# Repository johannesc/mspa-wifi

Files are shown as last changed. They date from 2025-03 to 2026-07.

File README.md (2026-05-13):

# mspa-wifi

This project explains how to add Wi-Fi connectivity to the M-Spa Aurora Urban U-AU062 using ESPHome,
enabling integration with Home Assistant. This is done by adding an ESP32-S2 module inside the
remote control that intercepts the traffic between the remote control and control box.

Note that currently this takes full control over the filter pump and heater which means that this will
disable the control of these from the remote control. The remote control can still be used to control
other functions (like UV and bubbles).

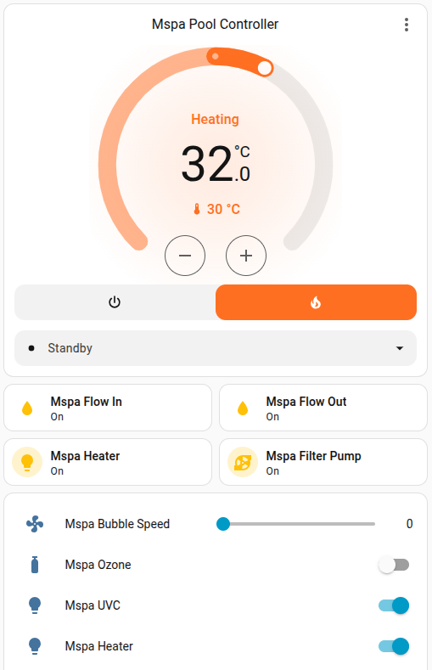
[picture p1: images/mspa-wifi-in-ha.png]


# Build your own

## Required Items

 * 1 pcs [S2 Mini V1.0.0 ESP32-S2 module](https://www.amazon.se/dp/B0BGPD6CV5)
 * 2 pcs [1k Ohm restistor](https://www.amazon.se/dp/B0DWK5KSBF)
 * [2.54 mm header](https://www.amazon.se/dp/B0DYDBSTGJ)
 * Connector for the remote
 * Some cables, soldering iron, glue gun etc.

## Program Your ESP-32 module, command line version

Read [Getting Started with the ESPHome Command Line](https://esphome.io/guides/getting_started_command_line/)

Download or clone the repository, e.g.:

```
git clone https://github.com/johannesc/mspa-wifi.git
```

Create a esphome/secrets.yaml with content:

```
wifi_ssid: <Your Wi-Fi SSID>
wifi_password: <Your Wi-Fi Passoword>

mspa_password: <A password of your choice>
mspa_api_key: <Home Assistant>
```

An esphome API key can be created [here](https://esphome.io/components/api.html)

Connect your module using a USB-C cable and program it (press and hold the "O" button while pressing and releasing the RST button to put in programming mode):
```
$ pip install esphome
$ cd esphome
$ esphome run mspa-wifi.yaml
```
## Add the Mspa device to Home Assistant

Go to Settings/Devices & Services/ESPHome and press "ADD DEVICE". If this is your first ESPHome
device you probably need to add the ESPHome integration first.

For more information see [Connecting your device to Home Assistant](https://esphome.io/guides/getting_started_hassio.html#connecting-your-device-to-home-assistant).

## If you don't have Home Assistant

Make sure to add `reboot_timeout: 0s` to the `mspa-wifi.yaml` to prevent it from rebooting every 15 minutes.

## Modifying your Remote

Below picture shows how to connect your hardware. Everything fits inside the M-Spa remote control
(it is a bit tight though). The 1 k resistors are used to limit the current as the M-Spa uses 5 v
while the ESP32-S2 uses 3.3 v.

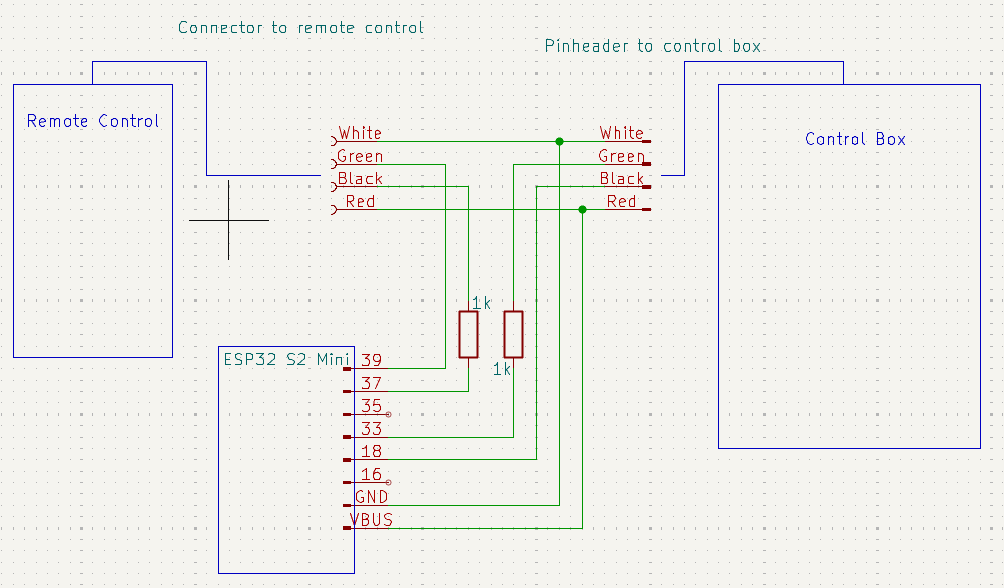
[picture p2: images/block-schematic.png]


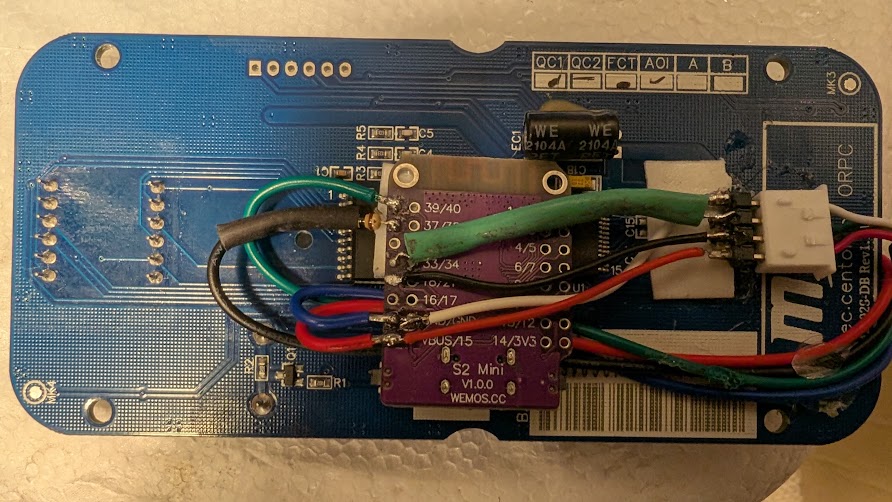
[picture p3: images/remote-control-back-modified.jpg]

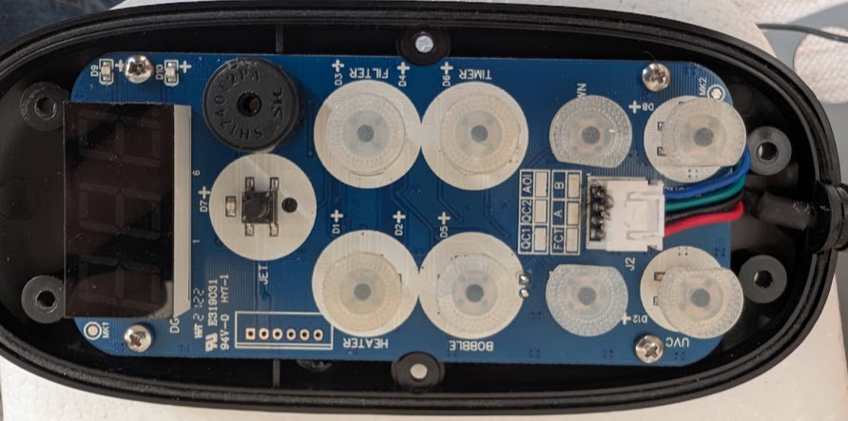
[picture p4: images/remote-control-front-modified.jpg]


## Ready To Use

You should now be ready to control your M-Spa through Home Assistant or through your browser
at [http://mspa.local/](http://mspa.local/).

# M-Spa protocol and Hardware Description

## Hardware

### Control Box
The control board inside the control box:
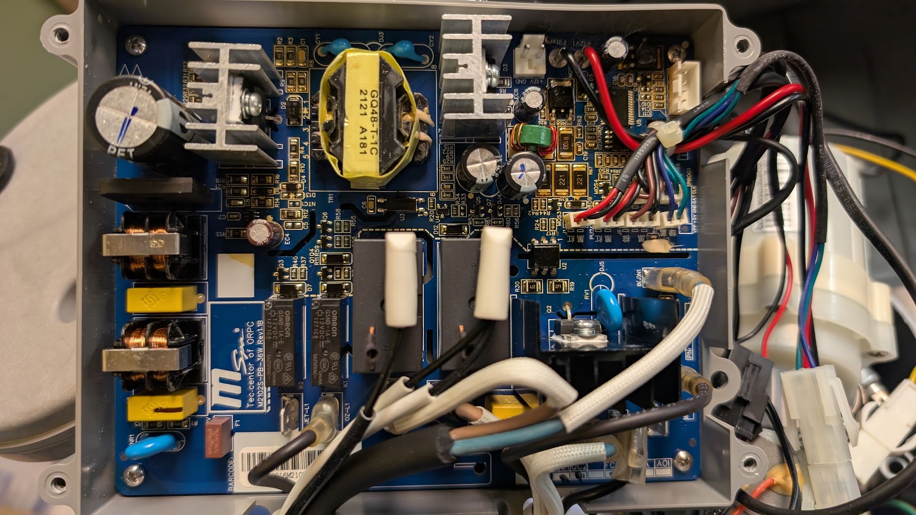
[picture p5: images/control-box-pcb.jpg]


The microcontroller is a PIC16F723A:

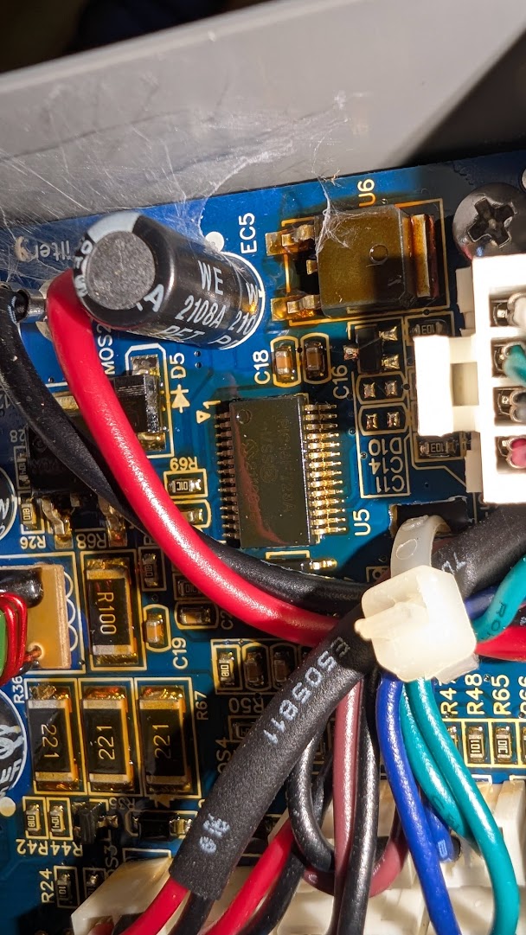
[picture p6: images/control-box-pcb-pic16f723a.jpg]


The connector to the remote control can be seen in the upper right corner. The pinout:

| Color | Description |
|---|---|
| White | GND |
| Green | Tx (control box to remote control) |
| Black | Rx (remote control to control box) |
| Red | +5v |

### Remote Control

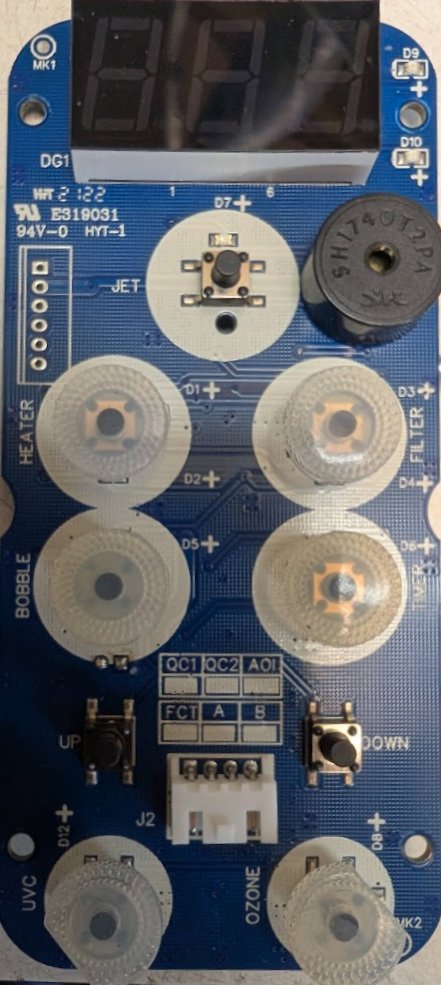
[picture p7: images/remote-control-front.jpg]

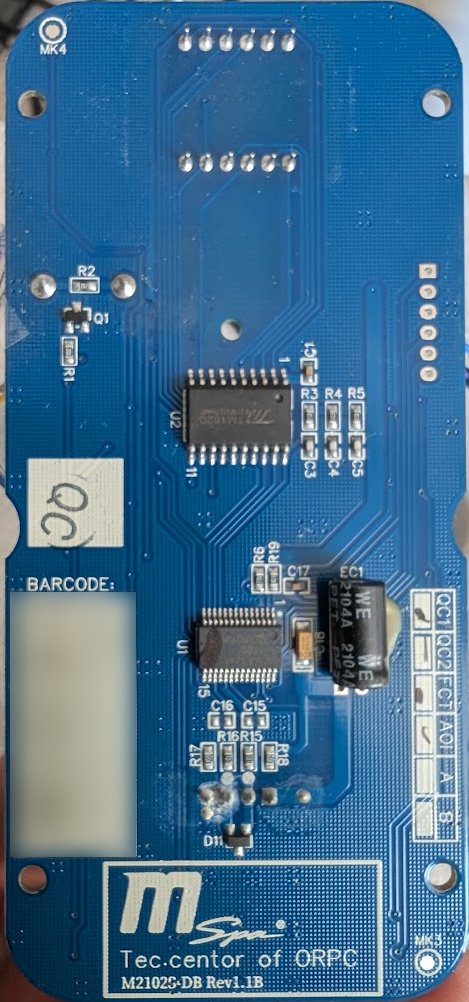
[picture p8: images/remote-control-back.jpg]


The microcontroller is a PIC16F723A. The chip at the top is a TM1620 (LED driver).

Unmounted Pin Header

| Pin # | Description |
|---|---|
| 1 (top) | PIC16F723A Pin #1 (/MCLR) |
| 2 | PIC16F723A Pin #19 (VDD) |
| 3 | GND |
| 4 | PIC16F723A Pin #28 (ICSPDAT) |
| 5 | PIC16F723A Pin #27 (ICSPCLK) |
| 6 | NC? |

## Protocol

UART Settings 9600 bps 8N1. 4 byte packets.

See `scripts/mspa_decoder.py` for example decoding of the protocol.

Captured data:

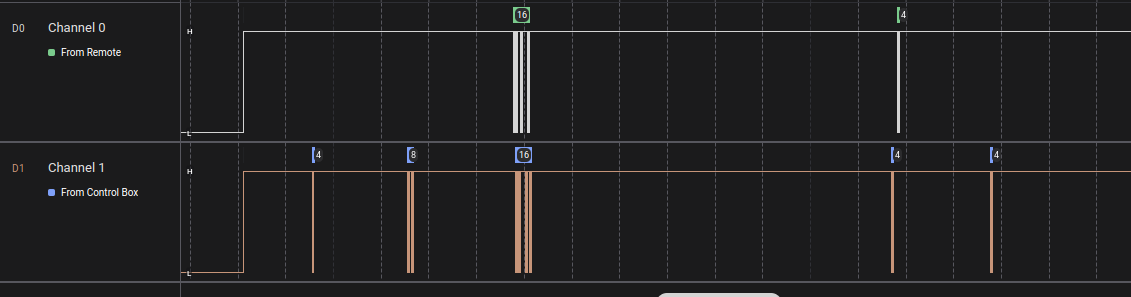
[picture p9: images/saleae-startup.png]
Captured startup communication


### Example Packets

#### From Control Box:
| Data | Description |
|---|---|
|0xA5  | Packet start |
|0x06  | Temperature reading |
|0x1C  | Temp = 0x1C/2 = 14.0 degrees  |
|0xC7  | Checksum = 0xA5 + 0x06 + 0X1C)|

More examples:

    0xA5 0x08 0x00 0xAD
    0xA5 0x0B 0x86 0x36

    Flow On?
    A5 08 01 AE

    A5 0B 86 36

#### From Remote

    Timestamp: Data
    0.30: A5 03 00 A8
    1.81: A5 0D 00 B2
    3.31: A5 0E 00 B3
    4.81: A5 15 00 BA
    4.91: A5 01 00 A6
    6.31: A5 02 00 A7

    Press - one time (temp at 40 degrees)
    110.67: A5 16 00 BB
    110.67: A5 04 28 D1

    Press - until 35 degrees:
    173.09: A5 04 23 CC

    Heater On:
    A5 02 01 A8
    A5 16 00 BB

    Filter On:
    A5 02 01 A8
    A5 16 00 BB

### Power On Sequence

    /dev/ttyUSB0: 5.46: New Command: A5 09 00 AE: Unknown command A5 09 00 AE
    /dev/ttyUSB0: 5.66: New Command: A5 07 0C B8: Unknown command A5 07 0C B8
    /dev/ttyUSB1: 5.89: New Command: A5 0B 00 B0: Unknown command A5 0B 00 B0
    /dev/ttyUSB1: 5.89: New Command: A5 0A 00 AF: Unknown command A5 0A 00 AF
    /dev/ttyUSB0: 5.89: New Command: A5 0B 86 36: Unknown command A5 0B 86 36
    /dev/ttyUSB0: 5.89: New Command: A5 0A 01 B0: Unknown command A5 0A 01 B0
    /dev/ttyUSB1: 5.90: New Command: A5 11 00 B6: Unknown command A5 11 00 B6
    /dev/ttyUSB0: 5.91: New Command: A5 11 00 B6: Unknown command A5 11 00 B6
    /dev/ttyUSB1: 5.91: New Command: A5 10 00 B5: Unknown command A5 10 00 B5
    /dev/ttyUSB0: 5.92: New Command: A5 10 00 B5: Unknown command A5 10 00 B5
    /dev/ttyUSB0: 6.06: New Command: A5 06 2F DA: Temp report: 23.5 °C
    /dev/ttyUSB1: 6.09: New Command: A5 01 00 A6: Heater enabled: False
    /dev/ttyUSB0: 6.87: New Command: A5 08 00 AD: Flow report: In: False, out: False
    /dev/ttyUSB0: 7.08: Old Command: A5 06 2F DA: Temp report: 23.5 °C
    /dev/ttyUSB1: 7.49: New Command: A5 02 00 A7: Set filter: False
    /dev/ttyUSB0: 7.89: Old Command: A5 08 00 AD: Flow report: In: False, out: False
    /dev/ttyUSB0: 8.09: Old Command: A5 06 2F DA: Temp report: 23.5 °C
    /dev/ttyUSB0: 8.90: Old Command: A5 08 00 AD: Flow report: In: False, out: False
    /dev/ttyUSB1: 8.99: New Command: A5 03 00 A8: Set bubble speed: 0
    /dev/ttyUSB0: 9.11: Old Command: A5 06 2F DA: Temp report: 23.5 °C
    /dev/ttyUSB0: 9.92: Old Command: A5 08 00 AD: Flow report: In: False, out: False
    /dev/ttyUSB0: 10.12: Old Command: A5 06 2F DA: Temp report: 23.5 °C
    /dev/ttyUSB1: 10.50: New Command: A5 0D 00 B2: Unknown command A5 0D 00 B2
    /dev/ttyUSB1: 10.90: New Command: A5 0F 00 B4: Unknown command A5 0F 00 B4
    /dev/ttyUSB0: 10.93: Old Command: A5 08 00 AD: Flow report: In: False, out: False
    /dev/ttyUSB0: 11.13: Old Command: A5 06 2F DA: Temp report: 23.5 °C
    /dev/ttyUSB0: 11.94: Old Command: A5 08 00 AD: Flow report: In: False, out: False
    /dev/ttyUSB1: 12.00: New Command: A5 0E 00 B3: Ozone enabled: False
    /dev/ttyUSB0: 12.15: Old Command: A5 06 2F DA: Temp report: 23.5 °C
    /dev/ttyUSB0: 12.96: Old Command: A5 08 00 AD: Flow report: In: False, out: False
    /dev/ttyUSB0: 13.16: Old Command: A5 06 2F DA: Temp report: 23.5 °C
    /dev/ttyUSB1: 13.51: New Command: A5 15 00 BA: Set UVC: False
    /dev/ttyUSB1: 13.61: Old Command: A5 01 00 A6: Heater enabled: False
    /dev/ttyUSB0: 13.97: Old Command: A5 08 00 AD: Flow report: In: False, out: False
    /dev/ttyUSB0: 14.17: Old Command: A5 06 2F DA: Temp report: 23.5 °C
    /dev/ttyUSB0: 14.98: Old Command: A5 08 00 AD: Flow report: In: False, out: False
    /dev/ttyUSB1: 15.01: Old Command: A5 02 00 A7: Set filter: False
    ....

#### Set Target Temp
    /dev/ttyUSB1: 75.14: Old Command: A5 02 00 A7: Set filter: False
    /dev/ttyUSB1: 75.57: Old Command: A5 01 00 A6: Heater enabled: False
    /dev/ttyUSB1: 75.57: Old Command: A5 02 00 A7: Set filter: False
    /dev/ttyUSB1: 75.57: Old Command: A5 03 00 A8: Set bubble speed: 0
    /dev/ttyUSB1: 75.57: Old Command: A5 0D 00 B2: Unknown command A5 0D 00 B2
    /dev/ttyUSB1: 75.57: Old Command: A5 0E 00 B3: Ozone enabled: False
    /dev/ttyUSB1: 75.57: Old Command: A5 15 00 BA: Set UVC: False
    /dev/ttyUSB1: 75.57: New Command: A5 16 00 BB: Unknown command A5 16 00 BB
    /dev/ttyUSB1: 75.57: New Command: A5 04 25 CE: Set temp: 37 °C
    /dev/ttyUSB0: 75.77: Old Command: A5 08 00 AD: Flow report: In: False, out: False
    /dev/ttyUSB0: 75.97: Old Command: A5 06 30 DB: Temp report: 24.0 °C
    /dev/ttyUSB1: 76.65: Old Command: A5 03 00 A8: Set bubble speed: 0
    /dev/ttyUSB0: 76.78: Old Command: A5 08 00 AD: Flow report: In: False, out: False
    /dev/ttyUSB0: 76.99: Old Command: A5 06 30 DB: Temp report: 24.0 °C
    /dev/ttyUSB0: 77.80: Old Command: A5 08 00 AD: Flow report: In: False, out: False
    /dev/ttyUSB0: 78.00: Old Command: A5 06 2F DA: Temp report: 23.5 °C
    /dev/ttyUSB1: 78.15: Old Command: A5 0D 00 B2: Unknown command A5 0D 00 B2

### Decoded Protocol

| Offset | Description |
|---|---|
| 0 | Packet start |
| 1 | Command (see table below) |
| 2 | Parameter |
| 3 | Checksum (sum of offset 0, 1, 2)|

| Command | Description |
|---|---|
| 0x01 | Set Heater |
| 0x02 | Set Filter |
| 0x03 | Set Bubble |
| 0x04 | Set Target Temperature |
| 0x05 | ? |
| 0x06 | Temp Report (sent each second)  |
| 0x07 | ? |
| 0x08 | Flow Report (sent each second)  |
| 0x09 | ? |
| 0x0A | ? |
| 0x0B | Get/Report timer. Sent 1 / min from remote (value 0x00) filter pump replies direct with a value that increase for every hour |
| 0x0C | ? |
| 0x0D | Sent 8 times / min (7.5 s period) from remote |
| 0x0E | Set Ozone |
| 0x0F | ? |
| 0x10 | ? |
| 0x11 | ? |
| 0x12 | ? |
| 0x13 | ? |
| 0x14 | ? |
| 0x15 | Set UVC |
| 0x16 | Inflate |
| 0x17 | ? |

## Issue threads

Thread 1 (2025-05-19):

Failed config on component

Rav3nholm, 2025-05-19:
Been trying to get this to work on my MSPA but have run into problems.
Don't know if its on my end the issue lies or something else.

Have a ESP32 S2 up and running with a base code but I cant get your code to work.
Get this error when validating:

`INFO ESPHome 2024.12.4
INFO Reading configuration /config/esphome/mspa.yaml...
ERROR Unable to load component mspa_wifi:
Traceback (most recent call last):
  File "/esphome/esphome/loader.py", line 177, in _lookup_module
    module = importlib.import_module(f"esphome.components.{domain}")
             ^^^^^^^^^^^^^^^^^^^^^^^^^^^^^^^^^^^^^^^^^^^^^^^^^^^^^^^
  File "/usr/lib/python3.11/importlib/__init__.py", line 126, in import_module
    return _bootstrap._gcd_import(name[level:], package, level)
           ^^^^^^^^^^^^^^^^^^^^^^^^^^^^^^^^^^^^^^^^^^^^^^^^^^^^
  File "<frozen importlib._bootstrap>", line 1206, in _gcd_import
  File "<frozen importlib._bootstrap>", line 1178, in _find_and_load
  File "<frozen importlib._bootstrap>", line 1149, in _find_and_load_unlocked
  File "<frozen importlib._bootstrap>", line 690, in _load_unlocked
  File "<frozen importlib._bootstrap_external>", line 936, in exec_module
  File "<frozen importlib._bootstrap_external>", line 1074, in get_code
  File "<frozen importlib._bootstrap_external>", line 1004, in source_to_code
  File "<frozen importlib._bootstrap>", line 241, in _call_with_frames_removed
  File "/config/esphome/components/mspa_wifi/__init__.py", line 7
    <!DOCTYPE html>
    ^
SyntaxError: invalid syntax
Failed config

mspa_wifi: [source /config/esphome/mspa.yaml:59]

  Component not found: mspa_wifi.
  - id: mspa_wifi_1
    uart_box_to_remote_id: uart_box_to_remote
    uart_remote_to_box_id: uart_remote_to_box`

Am not used to components and Python in ESPhome so it could be that I have missed something.
I have installed this manually on in my HA environment and not through "PIP".

Would love to make this work and help you out in testing, have 2 MSPA hot tubs of different models that could be used in testing.

Rav3nholm, 2025-05-21:
This is my mspa.yaml

```yaml
esphome:
  name: mspa
  friendly_name: MSPA

esp32:
  board: esp32-s2-saola-1
  framework:
    type: arduino

# Enable logging
logger:
  level: INFO  # Set to DEBUG if you are having issues!

api:
  encryption:
    key: "xxx"

ota:
  - platform: esphome
    password: "xxx"

wifi:
  ssid: !secret wifi_ssid
  password: !secret wifi_password

  # Enable fallback hotspot (captive portal) in case wifi connection fails
  ap:
    ssid: "Mspa Fallback Hotspot"
    password: "xxx"

captive_portal:

external_components:
  # use rtttl and dfplayer from ESPHome's dev branch in GitHub
  - source:
      type: git
      url: https://github.com/johannesc/mspa-wifi
      ref: main
    components: [ mspa_wifi ]

uart:
  - id: uart_box_to_remote
    rx_pin: # green cable to box
      number: GPIO33
      inverted: false
    tx_pin: # green cable to remote
      number: GPIO39
      inverted: false
    baud_rate: 9600
    rx_buffer_size: 512
  - id: uart_remote_to_box
    rx_pin: # black cable to remote
      number: GPIO37
      inverted: false
    tx_pin: # black cable to box
      number: GPIO18
      inverted: false
    baud_rate: 9600
    rx_buffer_size: 512

mspa_wifi:
  - id: mspa_wifi_1
    uart_box_to_remote_id: uart_box_to_remote
    uart_remote_to_box_id: uart_remote_to_box

binary_sensor:
  - platform: mspa_wifi
    flow_in:
      name: "Flow In"
    flow_out:
      name: "Flow Out"
    filter_pump:
      name: "Filter Pump"
    uvc:
      name: "UVC"
    ozone:
      name: "Ozone"
    heater:
      name: "Heater"

sensor:
  - platform: mspa_wifi
    water_temperature:
      name: "Temperature"
  - platform: mspa_wifi
    target_water_temperature:
      name: "Target Temperature"
      on_value:
      - lambda: |-
          id(target_water_temp).publish_state(x);
  - platform: mspa_wifi
    bubble_speed:
      name: "Bubble Speed"
      on_value:
      - lambda: |-
          id(target_bubble_speed).publish_state(x);
number:
  - platform: template
    name: "Target water temp"
    id: target_water_temp
    min_value: 24
    max_value: 40
    step: 1
    icon: "mdi:thermometer"
    optimistic: true
    restore_value: false
    set_action:
      - lambda: |-
          ESP_LOGI("number_template", "New value from HA: %f", x);
          id(mspa_wifi_1)->set_target_water_temperature(x);
  - platform: template
    name: "Bubble Speed"
    id: target_bubble_speed
    min_value: 0
    max_value: 3
    step: 1
    optimistic: false
    restore_value: false
    set_action:
      - lambda: |-
          ESP_LOGI("bubble speed template", "New value from HA: %f", x);
          id(mspa_wifi_1)->set_bubble_speed((uint8_t)x);
```
Now after I modified the component part of my code it does validate and writes to my ESP32 so that great!
I havent tried it on my SPA yet, will do that later this week or weekend.
Reporting back on the results then!

Closed 2025-06-06.

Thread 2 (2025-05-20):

filter pump switches off after few minutes

phrozendevil, 2025-05-20:
Hi Johannes, first if all... a really great project!
I built and flashed the ESP-module succesfully whithout problems after a little research with ESPHome and python.

The main problem is when i switch on the filter pump over remote, after a few minutes it switches off, so i can't let it run over night.
Also the correct state of UVC isn't shown in WebUI, how to find out which command-byte it has?

Is it possible to add action buttons for all functions in the WebUI when i directly connect to mspa.local? because i have no HomeAssistant

btw i have an MSpa Ottoman with UVC and Bubble (but without speed setting

sorry for writing this all in the issues, but i don't know how to contact you otherwise

best regards from germany
Thorsten

phrozendevil, 2025-05-20:
it looks like 0x10 is my UVC, with this i see the state

johannesc, 2025-05-20:
Hi Thorsten,

Great that you got started! I did this project as a "winter"-project so that I could use it once I had my pool up an running. Unfortunately the pool is still not up, so I have not tested the filter more than a short time.

But one problem with my solution is that for some commands the remote repeat the command at an interval. This means that if I turn on the air (bubble) pump, the remote is not aware of the change and will turn it off again, In order to get around this I intercept the commands from the remote and, if overridden (i.e. changed from HA), I overwrite the value in the packet with the HA one.  If you then change the value on the remote again, the remote is in control again. You can see this in the code:

```
     case CMD_SET_BUBBLE:
      {
        uint8_t bubble_speed = packet_[2];

        if (bubble_speed != bubble_remote_) {
          // The bubble speed was changed at the remote
          // The remote is now "in control"
          bubble_remote_ = bubble_speed;
          actual_state_.bubble = bubble_speed;
        } else if (bubble_speed != actual_state_.bubble) {
          packet_[2] = actual_state_.bubble;
          fill_crc(packet_);
          ESP_LOGI(TAG, "%s: Bubble speed is overridden from %d to %d", name_, bubble_speed, actual_state_.bubble);
        }
```

 I suspect that a similar solution is needed for other commands.

Regarding your question about the WebUI it should be possible to add full control. So far I only added the "Bubble Speed" and "Target Water Temperature". The WebUI have the same control possibility as in Home Assistant. I am not that good at ESPHome yaml, but you should be able to add more in a similar way as I have done. For on/off items perhaps you could use a  ["switch" template](https://www.home-assistant.io/integrations/switch.template/)?

I wish I had more time, but maybe I get some more during the summer. Otherwise you are always welcome to make pull-requests if you do any improvements.

phrozendevil, 2025-05-26:
Hi Johannes,

the filter pump is running now without problems. The problem was because i have no HomeAssistant, so the EspHome does a automatic reboot every 15 minutes. I added "reboot_timeout: 0s" in the mspa-wifi.yaml and now it stays on.

i'm about to make additions for the buttons in the webui, but i also have the problem with time ;-)

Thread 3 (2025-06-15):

Set temperature not working

CTBruker, 2025-06-15:
Hi first thanks for the great work! Set bubbles and all get values are working as expected! But setting  the temperature in home assistant do not have any effect of the set temperature in the remote control!

phrozendevil, 2025-06-19:
The main problem is that the remote overwrites all commands from ESP, you have to catch them and modify them before sending to pool. I added the switching of all functions and modified the heating part to switch off heater when target temp is reached. I don't know how to do a pullrequest, may johannesc can add the changes to his version!?
But it's still a develop version, i didn't test all circumstances.
Some things are in german, just edit them ;-) Best regards from Germany!

mspa_wifi.cpp
`#include "mspa_wifi.h"
#include "esphome/core/log.h"
#include "esphome/core/hal.h"

#define MSPA_START_BYTE 0xA5
#define MSPA_PACKET_LEN 4
#define MAX_PACKET_TIME_MS 100

#define CMD_TEMP_REPORT 0x06
#define CMD_FLOW_REPORT 0x08

#define CMD_SET_HEATER 0x01
#define CMD_SET_FILTER 0x02
#define CMD_SET_BUBBLE 0x03
#define CMD_SET_TARGET_TEMP 0x04
#define CMD_SET_OZONE 0x0E
#define CMD_SET_UVC 0x10    //can be 0x15 on other pools!
#define CMD_SET_UNKNOWN_0D 0x0D
#define CMD_SET_UNKNOWN_16 0x16

#define TAG "MspaWifi"

namespace esphome
{
  namespace mspa_wifi
  {
    void MspaWifi::setup()
    {
      mspa_box_to_remote_ = new MspaCom(box_to_remote_uart_, this, "-->");
      mspa_remote_to_box_ = new MspaCom(remote_to_box_uart_, this, "<--");
    }

    void MspaWifi::MspaCom::fill_crc(uint8_t *packet)
    {
      uint8_t crc = 0;
      for (int i = 0; i < (MSPA_PACKET_LEN - 1); i++)
      {
        crc += packet[i];
      }
      packet[3] = crc;
    }

    void MspaWifi::set_bubble_speed(uint8_t speed)
    {
      mspa_remote_to_box_->set_bubble_speed(speed);
    }

    void MspaWifi::set_switch_command(uint8_t command_id, bool enabled)
    {
      switch (command_id)
      {
        case CMD_SET_HEATER:
		  if (enabled) mspa_remote_to_box_->set_filter(enabled);
          mspa_remote_to_box_->set_heater(enabled);
          break;
        case CMD_SET_FILTER:
          mspa_remote_to_box_->set_filter(enabled);
          break;
        case CMD_SET_OZONE:
		  if (enabled) mspa_remote_to_box_->set_filter(enabled);
          mspa_remote_to_box_->set_ozone(enabled);
          break;
        case CMD_SET_UVC:
		  if (enabled) mspa_remote_to_box_->set_filter(enabled);
          mspa_remote_to_box_->set_uvc(enabled);
          break;
      }
    }

    void MspaWifi::MspaCom::set_bubble_speed(uint8_t speed)
    {
      // This will be used in handle_packet
      actual_state_.bubble = speed;
      mspa_->bubble_speed_sensor_->publish_state(actual_state_.bubble);

      // Also send a packet directly so that bubble speed is updated directly
      uint8_t packet[MSPA_PACKET_LEN] = {MSPA_START_BYTE, CMD_SET_BUBBLE, speed, 0};
      fill_crc(packet);
      send_packet(packet);
    }

    void MspaWifi::set_target_water_temperature(float target)
    {
      mspa_remote_to_box_->set_target_water_temperature(target);
      target_water_temperature_sensor_->publish_state(target);
    }

    void MspaWifi::MspaCom::set_target_water_temperature(float target)
    {
      ESP_LOGI(TAG, "Set target temp to %f", target);
      uint8_t packet[MSPA_PACKET_LEN] = {MSPA_START_BYTE, CMD_SET_TARGET_TEMP, (uint8_t)target, 0};
      fill_crc(packet);
      send_packet(packet);
    }

    void MspaWifi::MspaCom::set_heater(bool enabled)
    {
      actual_state_.heater = enabled;
	  ESP_LOGI(TAG, "Set heater %s", enabled ? "ENABLE" : "DISABLE");
      uint8_t data = enabled ? 1 : 0;
      uint8_t packet[MSPA_PACKET_LEN] = {MSPA_START_BYTE, CMD_SET_HEATER, data, 0};
      fill_crc(packet);
      send_packet(packet);
    }

    void MspaWifi::MspaCom::set_filter(bool enabled)
    {
	  actual_state_.filter = enabled;
      ESP_LOGI(TAG, "Set filter %s", enabled ? "ENABLE" : "DISABLE");
      uint8_t data = enabled ? 1 : 0;
      uint8_t packet[MSPA_PACKET_LEN] = {MSPA_START_BYTE, CMD_SET_FILTER, data, 0};
      fill_crc(packet);
      send_packet(packet);
    }

    void MspaWifi::MspaCom::set_ozone(bool enabled)
    {
      actual_state_.ozone = enabled;
	  ESP_LOGI(TAG, "Set ozone %s", enabled ? "ENABLE" : "DISABLE");
      uint8_t data = enabled ? 1 : 0;
      uint8_t packet[MSPA_PACKET_LEN] = {MSPA_START_BYTE, CMD_SET_OZONE, data, 0};
      fill_crc(packet);
      send_packet(packet);
    }

    void MspaWifi::MspaCom::set_uvc(bool enabled)
    {
      actual_state_.uvc = enabled;
	  ESP_LOGI(TAG, "Set uvc %s", enabled ? "ENABLE" : "DISABLE");
      uint8_t data = enabled ? 1 : 0;
      uint8_t packet[MSPA_PACKET_LEN] = {MSPA_START_BYTE, CMD_SET_UVC, data, 0};
      fill_crc(packet);
      send_packet(packet);
    }

    void MspaWifi::MspaCom::send_packet(const uint8_t *packet)
    {
      ESP_LOGI(TAG, "%s: Send packet: %02X %02X %02X %02X", name_, packet[0], packet[1], packet[2], packet[3]);
      for (int i = 0; i < MSPA_PACKET_LEN; i++)
      {
        uart_->write_byte(packet[i]);
      }
    }

    bool MspaWifi::MspaCom::handle_packet()
    {
      uint8_t crc = 0;
      for (int i; i < (MSPA_PACKET_LEN - 1); i++)
      {
        crc += packet_[i];
      }

      if (crc != packet_[MSPA_PACKET_LEN - 1])
      {
        ESP_LOGE(TAG, "%s: Bad CRC", name_);
        return false;
      }

      switch (packet_[1])
      {
      case CMD_TEMP_REPORT:
      {
        float water_temperature = (float)packet_[2] / 2.0f;
		ESP_LOGI(TAG, "%s: Water temp report %f", name_, water_temperature);
        mspa_->water_temperature_sensor_->publish_state(water_temperature);
        break;
      }
      case CMD_FLOW_REPORT:
      {
        bool flow_in = (packet_[2] & 0x01) != 0;
        bool flow_out = (packet_[2] & 0x02) != 0;
        ESP_LOGI(TAG, "%s: Flow in: %s, out: %s", name_, flow_in ? "On" : "Off", flow_out ? "On" : "Off");
        mspa_->flow_in_binary_sensor_->publish_state(flow_in);
        mspa_->flow_out_binary_sensor_->publish_state(flow_out);
        break;
      }
      case CMD_SET_TARGET_TEMP:
      {
        float target_temperature = packet_[2];
        mspa_->target_water_temperature_sensor_->publish_state(target_temperature);
        ESP_LOGI(TAG, "%s: Set target temp %f", name_, target_temperature);
        break;
      }
      case CMD_SET_HEATER:
      {
        bool heater_enabled = packet_[2];

        if (heater_enabled != remote_state_.heater) {
		  remote_state_.heater = heater_enabled;
		  actual_state_.heater = heater_enabled;
	    } else if (heater_enabled != actual_state_.heater) {
			if (mspa_->water_temperature_sensor_->has_state() && mspa_->target_water_temperature_sensor_->has_state() &&
    (actual_state_.heater == 1) && (mspa_->water_temperature_sensor_->get_state() >= mspa_->target_water_temperature_sensor_->get_state())) {
			  packet_[2] = 0x00;
		      fill_crc(packet_);
			  ESP_LOGI(TAG, "%s: Water temp %.1f reached target temp %.1f, NOT heating till temp falls", name_, mspa_->water_temperature_sensor_->get_state(), mspa_->target_water_temperature_sensor_->get_state());
		  } else {
			  packet_[2] = actual_state_.heater;
		      fill_crc(packet_);
		      ESP_LOGI(TAG, "%s: Heater state is overridden from %d to %d", name_, heater_enabled, actual_state_.heater);
		  }
		}

        if (mspa_->heater_switch_)
        {
          mspa_->heater_switch_->publish_state(actual_state_.heater);
        }
        ESP_LOGI(TAG, "%s: Heater enabled: %s", name_, actual_state_.heater ? "true" : "false");
		ESP_LOGI(TAG, "%s: Heater remote state: %s", name_, remote_state_.heater ? "true" : "false");

        break;
      }
      case CMD_SET_FILTER:
      {
        bool filter_enabled = packet_[2];

		if (filter_enabled != remote_state_.filter) {
		  remote_state_.filter = filter_enabled;
		  actual_state_.filter = filter_enabled;
	    } else if (filter_enabled != actual_state_.filter) {
		  packet_[2] = actual_state_.filter;
		  fill_crc(packet_);
		  ESP_LOGI(TAG, "%s: Filter state is overridden from %d to %d", name_, filter_enabled, actual_state_.filter);
		}
        if (mspa_->filter_pump_switch_ != NULL)
        {
          mspa_->filter_pump_switch_->publish_state(actual_state_.filter);
        }
        ESP_LOGI(TAG, "%s: Filter enabled: %s", name_, actual_state_.filter ? "true" : "false");
		ESP_LOGI(TAG, "%s: Filter remote state: %s", name_, remote_state_.filter ? "true" : "false");
        break;
      }
      case CMD_SET_BUBBLE:
      {
        uint8_t bubble_speed = packet_[2];

        if (bubble_speed != remote_state_.bubble) {
          // The bubble speed was changed at the remote
          // The remote is now "in control"
          remote_state_.bubble = bubble_speed;
          actual_state_.bubble = bubble_speed;
        } else if (bubble_speed != actual_state_.bubble) {
          packet_[2] = actual_state_.bubble;
          fill_crc(packet_);
          ESP_LOGI(TAG, "%s: Bubble speed is overridden from %d to %d", name_, bubble_speed, actual_state_.bubble);
        }

        mspa_->bubble_speed_sensor_->publish_state(packet_[2]);
        ESP_LOGI(TAG, "%s: Bubble speed: %d", name_, packet_[2]);
        break;
      }
      case CMD_SET_OZONE:
      {
        bool ozone_enabled = packet_[2] == 0x01;
        if (ozone_enabled != remote_state_.ozone) {
		  remote_state_.ozone = ozone_enabled;
		  actual_state_.ozone = ozone_enabled;
	    } else if (ozone_enabled != actual_state_.ozone) {
		  packet_[2] = actual_state_.ozone;
		  fill_crc(packet_);
		  ESP_LOGI(TAG, "%s: Ozone state is overridden from %d to %d", name_, ozone_enabled, actual_state_.ozone);
		}
		if (mspa_->ozone_switch_)
        {
          mspa_->ozone_switch_->publish_state(actual_state_.ozone);
        }
        ESP_LOGI(TAG, "%s: Ozone enabled: %s", name_, actual_state_.ozone ? "true" : "false");
		ESP_LOGI(TAG, "%s: Ozone remote state: %s", name_, remote_state_.filter ? "true" : "false");
        break;
      }
      case CMD_SET_UVC:
      {
        bool uvc_enabled = packet_[2];
		if (uvc_enabled != remote_state_.uvc) {
		  remote_state_.uvc = uvc_enabled;
		  actual_state_.uvc = uvc_enabled;
	    } else if (uvc_enabled != actual_state_.uvc) {
		  packet_[2] = actual_state_.uvc;
		  fill_crc(packet_);
		  ESP_LOGI(TAG, "%s: UVC state is overridden from %d to %d", name_, uvc_enabled, actual_state_.uvc);
		}
        if (mspa_->uvc_switch_)
        {
          mspa_->uvc_switch_->publish_state(actual_state_.uvc);
        }
        ESP_LOGI(TAG, "%s: UVC enabled: %s", name_, actual_state_.uvc ? "true" : "false");
		ESP_LOGI(TAG, "%s: UVC remote state: %s", name_, remote_state_.filter ? "true" : "false");
        break;
      }
      default:
      {
        ESP_LOGE(TAG, "%s: Unknown packet: %02X %02X %02X %02X", name_, packet_[0], packet_[1], packet_[2], packet_[3]);
        break;
      }
      }
      return true;
    }
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
Randolf22, 2025-06-19:
Hi,

Just to confirm – for you, is the heating control actually working, including setting the target temperature?

I’ve now tested everything via the web interface as well, but the behavior remains the same: the heating turns off automatically after a few seconds, and setting a target temperature has no effect.

Additionally, I’ve noticed that I’m seeing some “unknown packages” in the logs or data stream. Do you see the same on your side?

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

phrozendevil, 2025-06-19:
Maybe i changed other files too, i will have a look later.

phrozendevil, 2025-06-23:
here are all my files with timer control for the heater. but because my pool has only one bubble speed i changed this to a normal switch, the original code is commented out. Webinterface V3 and the most in german.
maybe JohannesC can combine this with his code? or i finally find out how a pullrequest works ;-)

[https://drive.google.com/file/d/15JLOBKLaJK6sBXwsAFC9FcnZAyIB6S4e/view?usp=sharing](url)

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

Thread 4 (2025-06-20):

step-by-step instructions?

schnaidi, 2025-06-20:
Hey, hey, first of all, thank you so much for putting in the effort and trying everything to get the pools working. You have my deepest respect and appreciation.

I'm a complete noob, and this is all completely new territory for me.

But I would like to be able to control my pool via Home Assistant.

I can install the hardware easily, but unfortunately I can't get the programming and insertion, reading the data, etc. right. I've been trying for a week now, even though it's probably well explained.

But unfortunately, I can't get it to work.

Could someone write me a step-by-step guide on how to integrate something so that it works, or so that I at least see some progress and don't have to give up? :(

Or could someone send me a video showing what the integration with Home Assistant should look like, or how to integrate it?

phrozendevil, 2025-06-23:
Hey schnaidi,

where exactly does it fail? installing python? installing esphome?
do you have Windows or another OS?

schnaidi, 2025-06-23:
Hey, hey, first of all, thanks for your message and replying.

I read in the other post that you're also from Germany. Would it be possible to connect with you directly? I'm relatively new to this topic and I've probably made a few mistakes.
I managed to integrate it into Home Assistant, for example, but when I use the ESP32 on my remote control, for example, my remote doesn't work at all, or is that normal? And I don't get any data via Home Assistant.

The question can actually be closed or considered closed, since I've at least already gotten it into Home Assistant.

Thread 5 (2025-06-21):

Does this work with other MSpa?

gustafnilklint, 2025-06-21:
I have an MSpa where the "remote" is built into the external pump unit. Like this model:

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

Have anyone tried this project with such pump?

johannesc, 2025-06-25:
I have not tested with my own pool with a separate remote. What is the exact model of this one? When I search it looks like a "Mspa Naval F-NA062W" which seems to come with a phone application?

gustafnilklint, 2025-06-26:
Unfortunately my model is a bit older, with the pump-unit without Wifi capability.
I think the model is called MSpa MONO Frame or something similar.

gustafnilklint, 2025-08-07:
A bit of follow up on this topic:
I have put together the hardware and connected it to my spa.

It seem to be working to some extent. I can send commands that successfully toggle the heater, pump, bubbles and ozone. But after a few seconds the heater turn off again together with a beep from the remote.
But at least it seem to be able to send commands that is accepted by the box..

I cannot see any "state" from the pool. It is all showing as unavailable.

I see tons of logs like this:
"Bad start 0x00"

Any thoughts on what can be the reason behind these issues?

johannesc, 2025-08-10:
I am guessing that something is wrong with the receiving data from the pump unit. Check the connections to make sure that they are correct and properly connected.

I have still not put up my pool for this season and hence not tested this project in "real life". Maybe I get some time going forward, but until then, don't expect so much activity from my side here :)

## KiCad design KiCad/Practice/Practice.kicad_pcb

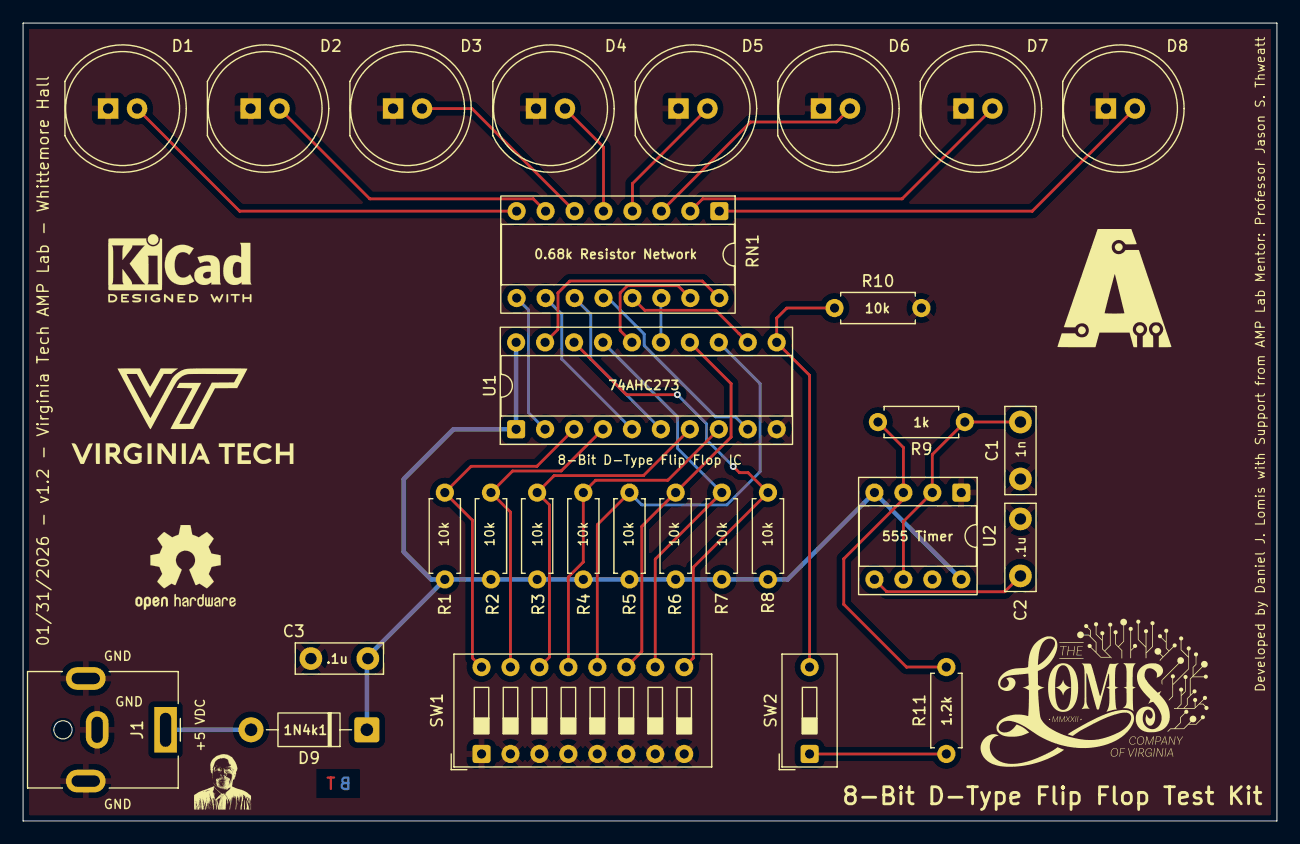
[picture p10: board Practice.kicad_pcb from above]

Board: 4 copper layers, 110.0 x 70.0 mm, 29 parts (0 on the bottom side), 32 nets.

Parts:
C1: 1n; C_Disc_D7.5mm_W2.5mm_P5.00mm
C2, C3: 100n; C_Disc_D7.5mm_W2.5mm_P5.00mm
D1, D2, D3, D4, D5, D6, D7, D8: LED; LED_D10.0mm
D9: 1N4001; D_DO-41_SOD81_P10.16mm_Horizontal
J1: Barrel_Jack_MountingPin; BarrelJack_CUI_PJ-063AH_Horizontal
R1, R2, R3, R4, R5, R6, R7, R8, R10: 10k; R_Axial_DIN0207_L6.3mm_D2.5mm_P7.62mm_Horizontal
R9: 1k; R_Axial_DIN0207_L6.3mm_D2.5mm_P7.62mm_Horizontal
R11: 1.2k; R_Axial_DIN0207_L6.3mm_D2.5mm_P7.62mm_Horizontal
RN1: R_Pack08; DIP-16_W7.62mm_Socket
SW1: SW_DIP_x08; SW_DIP_SPSTx08_Slide_9.78x22.5mm_W7.62mm_P2.54mm
SW2: SW_DIP_x01; SW_DIP_SPSTx01_Slide_9.78x4.72mm_W7.62mm_P2.54mm
U1: 74AHC273; DIP-20_W7.62mm_Socket
U2: ICM7555xP; DIP-8_W7.62mm_Socket

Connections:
+5V: C3.1, D9.1 (K), R1.1, R2.1, R3.1, R4.1, R5.1, R6.1, R7.1, R8.1, U1.1 (~Mr), U1.20 (VCC), U2.4 (R), U2.8 (VCC)
GND: C1.1, C2.2, C3.2, D1.1 (K), D2.1 (K), D3.1 (K), D4.1 (K), D5.1 (K), D6.1 (K), D7.1 (K), D8.1 (K), J1.2, J1.MP (MountPin), R10.2, SW1.1, SW1.2, SW1.3, SW1.4, SW1.5, SW1.6, SW1.7, SW1.8, U1.10 (GND), U2.1 (GND)
unnamed: D1.2 (A), RN1.8 (R8.1)
unnamed: D2.2 (A), RN1.7 (R7.1)
unnamed: D3.2 (A), RN1.6 (R6.1)
unnamed: D4.2 (A), RN1.5 (R5.1)
unnamed: D5.2 (A), RN1.4 (R4.1)
unnamed: D6.2 (A), RN1.3 (R3.1)
unnamed: D7.2 (A), RN1.2 (R2.1)
unnamed: D8.2 (A), RN1.1 (R1.1)
unnamed: D9.2 (A), J1.1
unnamed: R11.1, SW2.1
unnamed: RN1.16 (R1.2), U1.19 (Q7)
unnamed: RN1.15 (R2.2), U1.16 (Q6)
unnamed: RN1.14 (R3.2), U1.15 (Q5)
unnamed: RN1.13 (R4.2), U1.12 (Q4)
unnamed: RN1.12 (R5.2), U1.9 (Q3)
unnamed: RN1.11 (R6.2), U1.6 (Q2)
unnamed: RN1.10 (R7.2), U1.5 (Q1)
unnamed: RN1.9 (R8.2), U1.2 (Q0)
unnamed: R10.1, SW2.2, U1.11 (Cp)
unnamed: R1.2, SW1.16, U1.3 (D0)
unnamed: R2.2, SW1.15, U1.4 (D1)
unnamed: R3.2, SW1.14, U1.7 (D2)
unnamed: R4.2, SW1.13, U1.8 (D3)
unnamed: R5.2, SW1.12, U1.13 (D4)
unnamed: R6.2, SW1.11, U1.14 (D5)
unnamed: R7.2, SW1.10, U1.17 (D6)
unnamed: R8.2, SW1.9, U1.18 (D7)
unnamed: C2.1, U2.5 (CV)
unnamed: R9.2, R11.2, U2.3 (Q)
unnamed: C1.2, R9.1, U2.2 (TR), U2.6 (THR)

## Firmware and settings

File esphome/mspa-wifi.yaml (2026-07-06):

substitutions:
  device_name: mspa
  device_password: !secret mspa_password
  device_api_key: !secret mspa_api_key

esphome:
  name: ${device_name}
  on_boot:
    priority: -100
    then:
      - delay: 10s
      - number.set:
          id: mspa_bubble_speed
          value: 0
      - switch.turn_off: mspa_ozone_switch
      - switch.turn_on: mspa_uvc_switch

esp32:
  board: lolin_s2_mini
  variant: esp32s2
  framework:
    type: esp-idf

wifi:
  ssid: !secret wifi_ssid
  password: !secret wifi_password

  # Enable fallback hotspot (captive portal) in case wifi connection fails
  ap:
    ssid: "esp-${device_name}"
    password: "${device_password}"

captive_portal:

# Enable logging
logger:
  level: INFO  # Set to DEBUG if you are having issues!
  #baud_rate: 0 # disable logging over uart

api:
  encryption:
    key: "${device_api_key}"

ota:
  platform: esphome
  password: "${device_password}"

web_server:
  port: 80
  ota: false
#  auth:
#    username: admin
#    password: "${device_password}"

external_components:
  - source: components
    components: [ mspa_wifi ]

uart:
  - id: uart_box_to_remote
    rx_pin: # green cable to box
      number: GPIO33
      inverted: false
    tx_pin: # green cable to remote
      number: GPIO39
      inverted: false
    baud_rate: 9600
    rx_buffer_size: 512
  - id: uart_remote_to_box
    rx_pin: # black cable to remote
      number: GPIO37
      inverted: false
    tx_pin: # black cable to box
      number: GPIO18
      inverted: false
    baud_rate: 9600
    rx_buffer_size: 512

mspa_wifi:
  id: mspa_wifi_1
  uart_box_to_remote_id: uart_box_to_remote
  uart_remote_to_box_id: uart_remote_to_box
  uvc_command: 0x15
  jet_command: 0x0D

  # Sensors
  water_temperature:
    id: mspa_water_temperature
    name: "Temperature"
    state_class: "measurement"
    unit_of_measurement: "°C"
    device_class: "temperature"
    accuracy_decimals: 1

  # Binary sensors
  flow_in:
    name: "Flow In"
  flow_out:
    name: "Flow Out"

  # Switches
  filter_pump:
    name: "Filter Pump"
    on_turn_off:
      climate.control:
        id: climate_thermostat
        mode: "OFF"

  uvc:
    name: "UVC"
    id: mspa_uvc_switch

  ozone:
    name: "Ozone"
    id: mspa_ozone_switch
    restore_mode: ALWAYS_OFF
    on_turn_on:
      - script.execute: mspa_ozone_auto_off
    on_turn_off:
      - script.stop: mspa_ozone_auto_off

  heater:
    id: mspa_heater
    name: "Heater"

  jet:
    name: "Jet"
    id: mspa_jet_switch

  # Number controls
  target_water_temperature:
    name: "Target Temperature"
    id: mpsa_target_temperature
    min_value: 10

  bubble_speed:
    name: "Bubble Speed"
    id: mspa_bubble_speed
    max_value: 3
    on_value:
      then:
        - lambda: |-
            ESP_LOGI("yaml", "on_value: bubble_speed changed to %f", x);
        - if:
            condition:
              lambda: 'return x > 0;'
            then:
              - script.execute: mspa_bubble_speed_auto_off
            else:
              - script.stop: mspa_bubble_speed_auto_off

  inflate:
    name: "Inflate"
    id: mspa_inflate

script:
  - id: mspa_bubble_speed_auto_off
    mode: restart
    then:
      - delay: 300s
      - number.set:
          id: mspa_bubble_speed
          value: 0
  - id: mspa_ozone_auto_off
    mode: restart
    then:
      - delay: 7200s
      - switch.turn_off: mspa_ozone_switch

sensor:
  - platform: uptime
    type: seconds
    name: Uptime Sensor
  - platform: internal_temperature
    name: "Internal Temperature"
    id: int_temp

climate:
  - platform: thermostat
    name: "Pool Controller"
    id: climate_thermostat
    sensor: mspa_water_temperature
    min_heating_off_time: 10s
    min_heating_run_time: 10s
    min_idle_time: 10s
    visual:
      min_temperature: 10
      max_temperature: 40
      temperature_step: 0.5
    heat_action:
      - switch.turn_on: mspa_heater
    idle_action:
      - switch.turn_off: mspa_heater
    default_preset: Standby
    preset:
      - name: Hibernate
        default_target_temperature_low: 10
      - name: Standby
        default_target_temperature_low: 35
      - name: Swim
        default_target_temperature_low: 40
    on_state:
      - lambda: |-
          id(mpsa_target_temperature).control(x.target_temperature);

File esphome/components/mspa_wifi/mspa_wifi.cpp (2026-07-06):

#include "mspa_wifi.h"
#include "esphome/core/log.h"
#include "esphome/core/hal.h"

#define MSPA_START_BYTE 0xA5
#define MSPA_PACKET_LEN 4
#define MAX_PACKET_TIME_MS 100

#define CMD_TEMP_REPORT 0x06
#define CMD_FLOW_REPORT 0x08
#define CMD_TIMER_REPORT 0x0B

#define CMD_SET_HEATER 0x01
#define CMD_SET_FILTER 0x02
#define CMD_SET_BUBBLE 0x03
#define CMD_SET_TARGET_TEMP 0x04
#define CMD_GET_TIMER 0x0B
#define CMD_SET_OZONE 0x0E
#define CMD_SET_JET 0x0D
#define CMD_SET_INFLATE 0x16
#define CMD_JET_REPORT 0x18

#define TAG "MspaWifi"

namespace esphome
{
  namespace mspa_wifi
  {
    void MspaWifi::set_box_to_remote_uart(uart::UARTComponent *box_uart) {
      mspa_box_to_remote_ = new MspaBoxToRemoteCom(box_uart, this, "-->");
    }

    void MspaWifi::set_remote_to_box_uart(uart::UARTComponent *remote_uart) {
      mspa_remote_to_box_ = new MspaRemoteToBoxCom(remote_uart, this, uvc_command_, jet_command_, "<--");
    }

    void MspaWifi::MspaCom::fill_crc(uint8_t *packet)
    {
      uint8_t crc = 0;
      for (int i = 0; i < (MSPA_PACKET_LEN - 1); i++)
      {
        crc += packet[i];
      }
      packet[3] = crc;
    }

    void MspaWifi::set_bubble_speed(uint8_t speed)
    {
      mspa_remote_to_box_->set_bubble_speed(speed);
    }

    void MspaWifi::set_heater(bool enabled) {
      if (enabled) {
        set_filter(true); // Heater requires filter pump running, also enable that
      }
      mspa_remote_to_box_->set_heater(enabled);
    }

    void MspaWifi::set_filter(bool enabled) {
      mspa_remote_to_box_->set_filter(enabled);
    }

    void MspaWifi::set_ozone(bool enabled) {
      if (enabled) {
        set_filter(true); // Ozone requires filter pump running, also enable that
      }
      mspa_remote_to_box_->set_ozone(enabled);
    }

    void MspaWifi::set_uvc(bool enabled) {
      if (enabled) {
        set_filter(true); // UVC requires filter pump running, also enable that
      }
      mspa_remote_to_box_->set_uvc(enabled);
    }

    void MspaWifi::set_jet(bool enabled) {
      if (enabled) {
        set_filter(true); // Jet requires filter pump running, also enable that
      }
      mspa_remote_to_box_->set_jet(enabled);
    }

    void MspaWifi::set_inflate(bool enabled) {
      mspa_remote_to_box_->set_inflate(enabled);
    }

    void MspaWifi::set_target_water_temperature(float target)
    {
      mspa_remote_to_box_->set_target_water_temperature(target);
    }

    void MspaWifi::MspaRemoteToBoxCom::set_bubble_speed(uint8_t speed)
    {
      mspa_->actual_state_.bubble = speed; // This will be used in handle_packet

      if (mspa_->target_bubble_speed_number_ != NULL) {
        mspa_->target_bubble_speed_number_->publish_state(mspa_->actual_state_.bubble);
      }
      uint8_t packet[MSPA_PACKET_LEN] = {MSPA_START_BYTE, CMD_SET_BUBBLE, speed, 0};
      fill_crc(packet);
      send_packet(packet);
    }

    void MspaWifi::MspaRemoteToBoxCom::set_target_water_temperature(float target)
    {
      ESP_LOGI(TAG, "Set target temp to %f", target);
      if (mspa_->target_water_temperature_number_ != NULL) {
        mspa_->target_water_temperature_number_->publish_state(target);
      }
      uint8_t packet[MSPA_PACKET_LEN] = {MSPA_START_BYTE, CMD_SET_TARGET_TEMP, (uint8_t)target, 0};
      fill_crc(packet);
      send_packet(packet);
    }

    void MspaWifi::MspaRemoteToBoxCom::set_heater(bool enabled)
    {
      ESP_LOGI(TAG, "Set heater %s", enabled ? "ENABLE" : "DISABLE");
      mspa_->actual_state_.heater = enabled; // This will be used in handle_packet
      if (mspa_->heater_switch_) {
        mspa_->heater_switch_->publish_state(mspa_->actual_state_.heater);
      }
      uint8_t data = enabled ? 1 : 0;
      uint8_t packet[MSPA_PACKET_LEN] = {MSPA_START_BYTE, CMD_SET_HEATER, data, 0};
      fill_crc(packet);
      send_packet(packet);
    }

    void MspaWifi::MspaRemoteToBoxCom::set_filter(bool enabled)
    {
      ESP_LOGI(TAG, "Set filter %s", enabled ? "ENABLE" : "DISABLE");
      mspa_->actual_state_.filter = enabled; // This will be used in handle_packet
      mspa_->remote_state_.filter = enabled; // Keep in sync to prevent F1
      if (mspa_->filter_pump_switch_ != NULL) {
        mspa_->filter_pump_switch_->publish_state(mspa_->actual_state_.filter);
      }
      uint8_t data = enabled ? 1 : 0;
      uint8_t packet[MSPA_PACKET_LEN] = {MSPA_START_BYTE, CMD_SET_FILTER, data, 0};
      fill_crc(packet);
      send_packet(packet);
    }

    void MspaWifi::MspaRemoteToBoxCom::set_ozone(bool enabled)
    {
      ESP_LOGI(TAG, "Set ozone %s", enabled ? "ENABLE" : "DISABLE");
      mspa_->actual_state_.ozone = enabled; // This will be used in handle_packet
      if (mspa_->ozone_switch_) {
        mspa_->ozone_switch_->publish_state(mspa_->actual_state_.ozone);
      }
      uint8_t data = enabled ? 1 : 0;
      uint8_t packet[MSPA_PACKET_LEN] = {MSPA_START_BYTE, CMD_SET_OZONE, data, 0};
      fill_crc(packet);
      send_packet(packet);
    }

    void MspaWifi::MspaRemoteToBoxCom::set_uvc(bool enabled)
    {
      ESP_LOGI(TAG, "Set uvc %s", enabled ? "ENABLE" : "DISABLE");
      mspa_->actual_state_.uvc = enabled; // This will be used in handle_packet
      if (mspa_->uvc_switch_) {
        mspa_->uvc_switch_->publish_state(mspa_->actual_state_.uvc);
      }
      uint8_t data = enabled ? 1 : 0;
      uint8_t packet[MSPA_PACKET_LEN] = {MSPA_START_BYTE, uvc_command_, data, 0};
      fill_crc(packet);
      send_packet(packet);
    }

    void MspaWifi::MspaRemoteToBoxCom::set_jet(bool enabled)
    {
      ESP_LOGI(TAG, "Set jet %s", enabled ? "ENABLE" : "DISABLE");
      mspa_->actual_state_.jet = enabled; // This will be used in handle_packet
      if (mspa_->jet_switch_) {
        mspa_->jet_switch_->publish_state(mspa_->actual_state_.jet);
      }
      uint8_t data = enabled ? 1 : 0;
      uint8_t packet[MSPA_PACKET_LEN] = {MSPA_START_BYTE, jet_command_, data, 0};
      fill_crc(packet);
      send_packet(packet);
    }

    void MspaWifi::MspaRemoteToBoxCom::set_inflate(bool enabled)
    {
      ESP_LOGI(TAG, "Set inflate %s", enabled ? "ENABLE" : "DISABLE");
      if (mspa_->inflate_switch_) {
        mspa_->inflate_switch_->publish_state(enabled);
      }
      uint8_t data = enabled ? 1 : 0;
      uint8_t packet[MSPA_PACKET_LEN] = {MSPA_START_BYTE, CMD_SET_INFLATE, data, 0};
      fill_crc(packet);
      send_packet(packet);
    }

    void MspaWifi::MspaCom::send_packet(const uint8_t *packet)
    {
      ESP_LOGD(TAG, "%s: Send packet: %02X %02X %02X %02X", name_, packet[0], packet[1], packet[2], packet[3]);

      for (int i = 0; i < MSPA_PACKET_LEN; i++)
      {
        uart_->write_byte(packet[i]);
      }
    }
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

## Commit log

2025-04-04 Improve the esphome project
    Now using two UART:s to intercept the UART traffic both ways.
    Currently supports setting the target temperature.
    Mostly untested.
2025-04-28 Make it possible to set target and bubble speed from HA
    The bubble speed and target temperature can now be set from both
    Home Assistant and the remote.
2025-05-04 Add build instructions
    Add basic build instructions together with some pictures.
    [mspa-wifi.kicad_pcb, mspa-wifi.kicad_sch]
2025-06-08 Make it possible to control more things
    This changes the uvc, filter_pump, ozone and heater to switches
    instead of sensors.
    Currently very limited testing, and probably not yet working properly.
2025-12-21 Fix CRC calculation
    The loop counter was not properly initialized.
    Closes #9
    [mspa_wifi.cpp]
2025-12-21 Move yaml to component code and remove redundant sensors
    This makes the configuration cleaner.
2025-12-21 Move all configurations to "mspa_wifi"
    This collects all configurations belonging to this component in one
    place. Also:
    * Specify the "esp-idf" framework as thi will be the default in
    ESPHome 2026.1.0
    * Add config options for UVC command as this appear to differ
    between different pumps
2025-12-28 Automatically enable filter pump when needed
    UVC, Heater and Ozone requires that the filter pump is enabled, so
    enable that automatically.
2025-12-28 Add settings for temperature sensor
    This adds some settings for the temperature sensor so that it is
    logged in the long term statistics.
2025-12-31 Add min_value config option for target temperature
    This makes the setting easy to configur in the yaml file.
2025-12-31 Only update MSPA target temperature if it has changed from last
2025-12-31 Create MspaCom when registering UART
    This makes the code cleaner and avoids a state where MspaWifi component
    is not fully created.
    [mspa_wifi.cpp, mspa_wifi.h]
2025-12-31 Override more control commands from remote
    This adds override for target temp, filter, ozone and UVC so that
    they can be controlled from HA without having the remote overriding
    them.
2025-12-31 Add thermostate climate controller for the water temperature
    As the pool does not turn off the heater at target temperature
    this makes it easy to control it automatically from Home Assistant
    with a nice user interface.
2026-01-01 Set a couple of default values after reboot
    This sets a good initial state after reboot.
    [mspa-wifi.yaml]
2026-01-24 Set minimum temperature to 10°C and add hibernate preset
    This can be used to reduce the energy consumption when no bath
    is planned in the near future.
2026-01-28 Add timer command/response to protocol description
    Discovered this while looking more at some logs.
2026-01-28 Move state variables to MspaWifi class
    This avoids state duplication.
    [mspa_wifi.cpp, mspa_wifi.h]
2026-01-28 Avoid sending flow on if the remote thinks that the filter pump is off
    I discovered that the remote control often ended up just displaying
    "f1". This seems to get solved by don't sending "flow on" to it when
    the remote "thinks" that the filter pump is off.
    [mspa_wifi.cpp]
2026-01-28 Log timer command and reports
2026-05-13 Let HA take full control of heater and pump
    The remote control will do "Auto-filtration" for 60 minutes every
    8 hours when the spa is in stand-by mode. This means that it will
    cyclye the filter pump on and off. Before this change this caused
    the filter pump to turn ofd as the control was "given back" to the
    remote.
    After this change it is not possible to control the filter pump or
    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
2026-06-21 Fix misleading UVC state log and align override logic with ozone
    The UVC handler logged the remote packet value instead of the actual
    state forwarded to the control box, which made HA control appear broken
    when the remote kept syncing its own stale state.
    [mspa_wifi.cpp]
2026-07-02 Add jet/hydromassage support (command 0x0D)
    - Add jet switch controllable from both HA and physical remote
    - Add configurable jet_command (default 0x0D) in YAML
    - Handle box jet status report (0x18) without forwarding to remote
    - Sync remote_state_.filter when HA activates filter pump
    - Switch framework from arduino to esp-idf
